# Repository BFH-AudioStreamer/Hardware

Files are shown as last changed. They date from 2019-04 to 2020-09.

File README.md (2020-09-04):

BFH Logo

# Hardware

This repository contains all the schematics and pcb designs developed for the
Audio-Streamer project. Please visit the [wiki](https://bfh-audiostreamer.github.io/Hardware) for the hardware description and 
audio measurements.

You can find PDF files of the schematics and the PCB gerber files in the Release section.

## Prerequisites
- Altium Designer

## Changes
See [CHANGELOG.md](CHANGELOG.md).

## Wiki
[To get more information about the circuits design visit the project wiki.](https://bfh-audiostreamer.github.io/Hardware)

## Authors
- Stefan Lüthi (Maintainer)

## License
Copyright Stefan Lüthi 2019.
This documentation describes Open Hardware and is licensed under the
CERN OHL v. 1.2.

You may redistribute and modify this documentation under the terms of the
CERN OHL v.1.2. (http://ohwr.org/cernohl). This documentation is distributed
WITHOUT ANY EXPRESS OR IMPLIED WARRANTY, INCLUDING OF
MERCHANTABILITY, SATISFACTORY QUALITY AND FITNESS FOR A
PARTICULAR PURPOSE. Please see the CERN OHL v.1.2 for applicable
conditions

[CERN OHL V1.2 lincese](LICENSE.md)

### Disclaimer
*Ixora.SchLib*, *Ixora.PcbLib* and the *SchDoc*s in the *Carrier-Board-Apalis* 
directory originate from Toradex. Therefore, the CERN OHL lincese does not apply:

Copyright (c) Toradex AG. All rights reserved. All data is for information 
purposes only and not guaranteed for legal purposes. Information has been 
carefully checked and is believed to beaccurate; however, no responsibility is 
assumed for inaccuracies. Brand and product names are trademarks or registered 
trademarks of their respective owners. Specifications are subject to change 
without notice.

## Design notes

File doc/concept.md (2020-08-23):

# Concept

The concept was created for standalone streamer with a touch-screen interface.

Concept

## Power Supply

The streamer can be divided into two main sections: a noisy computer section and a sensitive analog section containing the DAC. To isolate noise from the sections they are galvanically isolated.

The mains power is filtered with feed through filter to remove noise from mains. The filter AC signal is fed to a AC/DC module for the computer section and converted to DC in the analog section with a transformer/rectifier circuit. The transformer circuit with following linear regulators should result in a low noise DC supply for the DAC. A linear regulator for the computer is not feasible, due the high power consumption (ca. 5W).

## Digital/Analog Converter

The DAC is powered from a clean power supply. The digital audio stream can be sourced from I2S. The control the DAC I2C or SPI can be used, depending on the DAC selection. As sigma delta DACs typically use the I2S MCLK as system clock, a jitter free clock should be provided. This is done by the low jitter oscillators which can be selected as MCLK.

The analog signal from the DAC is passed through a filter to remove aliasing effects. The main analog output of the device are the RCA connectors. However, as most DAC output a differential signal two XLR connectors are intended on the desing.

## Computer

A computer on a module (CoM) is used to stream audio from the internet to the DAC. This prototype is based on an Apalis iMX6Quad module from Toradex. Therefore the computer section consists of the carrier board for this module.

To establish an connection to the internet ethernet and WiFi are intended. Local playback is possible over a USB interface. As the CoM also features a PCIe interface an SSD can be used as audio storage.

The streamer can be configured in standalone or server mode. In standalone mode the user can choose and control the audio playback directly on the device. A touch-screen interfaced by parallel-RGB and I2C or HDMI and USB can be used for that purpose.

## Isolation

The whole design is split into three seperate parts: the mains (230V), analog and digital section. The sections are galvanically isolated to minimize the influence between each ohter. To isolate the signals between the computer and the DAC a digital isolator can be used.

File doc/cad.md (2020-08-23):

# CAD

The CAD design was done in Autodesk Fusion 360. The case desing for the first Prottype is shown below.

<iframe src="https://outlook28079.autodesk360.com/shares/public/SH919a0QTf3c32634dcfcd85dd2a94cc4ccb?mode=embed" width="800" height="600" allowfullscreen="true" webkitallowfullscreen="true" mozallowfullscreen="true"  frameborder="0"></iframe>

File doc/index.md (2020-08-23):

# Audio-Streamer Hardware Wiki

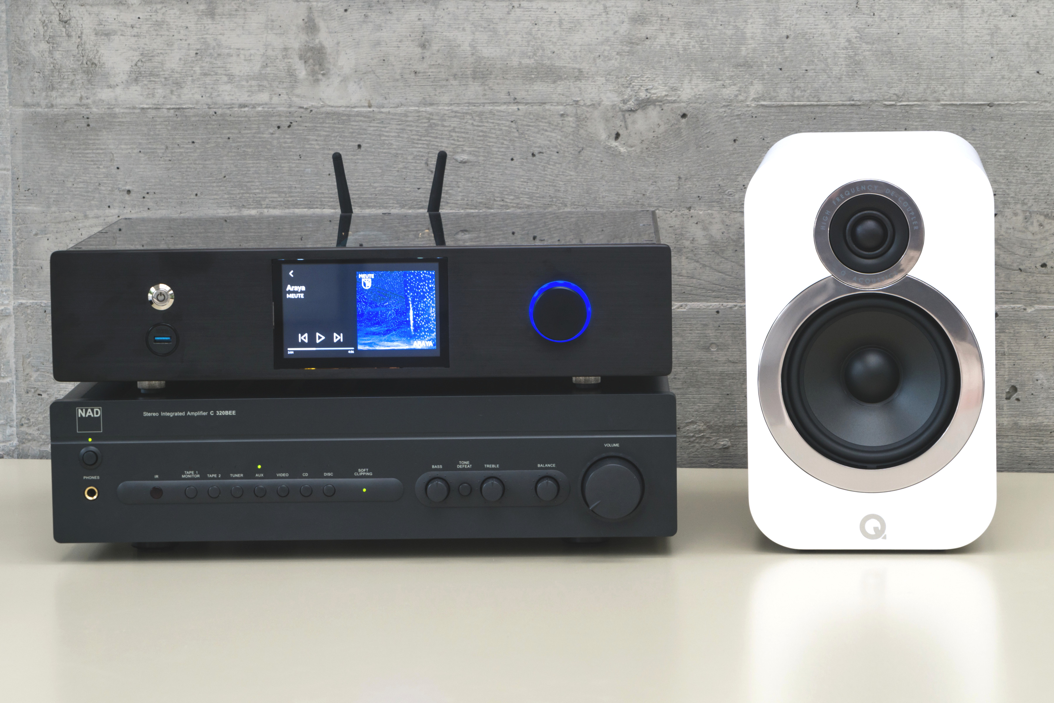
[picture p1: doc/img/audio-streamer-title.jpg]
audio-streamer-v1.0

First prototype of the audio-streamer with amplifier and speaker.

## Summary

The aim of this hardware project is to enable high-end audio equipment to play audio from streaming sources. Therefore, the audio-streamer is build with high-quality components. The modular concept allows the user/developer to change parts of the streamer to test different hardware components or to adjust the hardware to the users taste. The audio-streamer can be used with a touch-screen or as headless in HiFi rack.

## Structure

-   Concept
-   Modules
    -   Carrier boards
    -   DAC
    -   Filter
    -   Isolator
    -   Power supply
-   CAD
-   Measurements

## Present State

The second prototype (rev. 1.1) is being assembled. (2019-10-09)

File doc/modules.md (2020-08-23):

# Modules

The streamer was divided into several modules (PCBs) to be able to change to your favourite DAC or filter. But foremost to test and compare different circuit designs and component. The module groups are shown below.

## Carrier Board

A carrier board contains a socket for a module, as well as connectors for internal or external usage. They also contain the voltage regulators to supply the module.

Currently there are two carrier boards: on for the computer on a module (Toradex Apalis iMX6) and the digital to analog converter. With these two carrier boards the noisy digital and the sensitive analog circuits are separated.

## DAC

The DAC module contains an audio DAC with its circuitry. The performance of different DACs can be tested this way. Currently there exists a DAC module containing two AK4493 DACs.

## Filter

Every DAC needs a reconstruction filter. There are lots of operational amplifiers and different circuit designs available. To accommodate for the different performances the filter circuit can be swapped with a module.

## Isolator

To isolate the noisy digital circuit from the analog circuits a isolator module can be used.

## Power supply

The power supply converts mains AC to intermediate DC voltages for the carrier boards.

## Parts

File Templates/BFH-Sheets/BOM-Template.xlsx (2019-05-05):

Bill of Materials
Project: | Field=ProjectName |  |  |  |  |  | Field=Address1
 |  |  |  |  |  |  | Field=Address2
Author: | Field=DrawnBy | Revision: | Field=Revision |  |  |  | Field=Address3
Variant: | Field=VariantName | Date | Field=Date |  |  |  | Field=Address4
Column=Quantity | Column=Designator | Column=Comment | Column=Description | Column=Footprint | Column=Manufacturer Part No. | Distributor | Distributor Part No. | Price | Line Total
 |  |  |  |  |  |  |  |  | CHF 0.00
 |  |  |  |  |  |  |  |  | CHF 0.00
 |  |  |  |  |  |  |  |  | CHF 0.00
0 |  |  |  |  |  |  |  |  | CHF 0.00

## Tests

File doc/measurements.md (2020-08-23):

# Measurements

Coming as soon as the second prototype was tested.

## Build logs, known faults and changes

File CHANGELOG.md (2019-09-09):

# Changelogs

## Overview

- [Carrier-Board Apalis](#carrier-board-apalis)
- [Carrier-Board DAC](#carrier-board-dac)
- [DAC AK4493 Dual](#dac-ak4493-dual)
- [Encoder](#encoder)
- [Filter SallenKey](#filter-sk)
- [Isolator Mangetic](#isolator-mangetic)
- [Power Supply Unit](#psu)
- [Mainboard (discontinued)](#mainboard-discontinued)

## Carrier-Board Apalis

### V1.1 2019-09-09

#### Added
- Toradex Apalis carrier-board sections from [Mainboard 1.0](#mainboard-discontinued)
- Power off signal to CoM
- USB OTG interface for CoM flash access

#### Modified
- USB micro replaced by USB C connectors
- Fix footprint of HDMI2C1-6C1
- Fix schematic library error of M.2 Type B

#### Removed
- CoM signal LEDs

## Carrier-Board DAC

### V1.1 2019-09-09

#### Added
- DAC and power supply section from [Mainboard 1.0](#mainboard-discontinued)
- 0.1" connectors for DAC and filter modules

#### Modified
- Fix schematic library error of LT3094
- Fix overvoltage on voltage supervisor with voltage divider

## DAC AK4493 Dual

### V1.1 2019-09-09

#### Added
- DAC section from [Mainboard 1.0](#mainboard-discontinued)
- 5V voltage reference
- 0.1" connectors

#### Removed
- Reconstruction filter

## Encoder

### V1.0 2019-05-09

#### Added
- Rotary encoder with button
- 6 blue LEDs

## Filter SK

### V1.1 2019-09-09

#### Added
- Sallen-Key filter section from [Mainboard 1.0](#mainboard-discontinued)
- 0.1" connectors

#### Modified
- OPAMP footprint: SMD to DIP/SMD

#### Removed
- DC bias compensation

## Isolator Mangetic 

### V1.1 2019-09-09

#### Added
- Digital isolator section from [Mainboard 1.0](#mainboard-discontinued)
- 0.1" connectors

#### Modified
- SOIC wide footrpints replaced by SOIC narrow
- Fix pin mixup on the isolators

#### Removed
- Crystal oscillators

## PSU

### V1.0 2019-05-09

#### Added
- Analog power supply based on transformer, rectifier, caps
- Analog supply control with solid state relay (OptoMOS relay)
- Digital power supply based on AC/DC module

### V1.1 2019-09-09

#### Modified
- Fix schematic library error of CPC1926Y

## Mainboard (discontinued)

### V1.0 2019-05-09

#### Added
- Toradex Apalis carrier board based on the [Toradex Ixora source files](https://developer.toradex.com/products/ixora-carrier-board#design-resources)
- Net classes for high-speed signals
- Backlight control for parallel display output 
- Dual AK4493 DAC output
- Sallen-Key reconstruction filter
- Analog power supply with low noise linear regulators
- Digital signal isolation with magnetic low noise isolators
- Crystal oscillators for low jitter clock sources (22.5792 MHz and 24.5760 MHz)

#### Modified
- Apalis carrier board:
    - Minimal footprint size 0603 (imperial)
    - Altium project hierarchy changed from busses and labels to harnesses
    - Replaced obsolete components
    - M.2 connectors instead of mini PCIe connectors
    - Vertical ethernet connector instead of horizontal
    - Virtual COM port over USB instead of RS-232

#### Removed
- Apalis carrier board:
    - Fan control
    - Board ID EEPROM
    - SD card slot
    - Analog audio output
    - Camera interface
    - Resistive touch interface
    - LVDS display connector
    - CAN bus interface
    - Extension connector

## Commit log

2019-03-09 Add base project
    [Audio-Out.SchDoc, Hardware Achitecture.SchDoc, Mainboard.PrjPcb]
2019-03-09 Add Templates
    [BFH_BOM_Template.xlsm]
2019-03-09 Add Toradex Ixora Reference Board
    [Audio.SchDoc, CAN.SchDoc, Camera_Interface.SCHDOC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]
2019-03-09 Update Project File
    [Mainboard.PrjPcb]
2019-03-17 Add Audio Out
    [Audio-Out.SchDoc, Audio-Streamer-Mainboard.PcbDoc, Hardware Achitecture.SchDoc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]
2019-03-17 Add Audio Power Supply
    [Mainboard.PrjPcb]
2019-03-17 Ajust Project
    [Audio Power Supply.SchDoc, Audio-Out.SchDoc, Hardware Achitecture.SchDoc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]
2019-03-20 Add Ixora board and finish Audio-Out
    [Audio Power Supply.SchDoc, Audio-Out.SchDoc, Audio.SchDoc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]
2019-03-21 Add Isolator and improve DAC
    [Audio Power Supply.SchDoc, Audio-Out.SchDoc, DAC Interface.SchDoc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]
2019-03-24 Update Audio out and Power Supply
    [Audio Power Supply.SchDoc, Audio-Out.SchDoc]
2019-03-24 Update Analog stuff
    [Audio Power Supply.SchDoc, Audio-Out.SchDoc, DAC Interface.SchDoc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]
2019-03-30 Add Power Supply
    [Mainboard.PrjPcb, Power-Supply.PcbDoc, Power-Supply.PrjPcb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]
2019-03-30 Update Project
    [Audio Power Supply.SchDoc, Audio-Out.SchDoc, Mainboard.PrjPcb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]
2019-03-31 Update Part Numbers
    [Audio Power Supply.SchDoc, Audio-Out.SchDoc, DAC Interface.SchDoc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]
2019-04-01 Fix some schematic issues
    [Audio Power Supply.SchDoc, Audio-Out.SchDoc, DAC Interface.SchDoc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]
2019-04-02 Update all schematics
    [Audio-Out.SchDoc, DAC Interface.SchDoc, Digital Isolator.SchDoc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]
2019-04-03 Update Toradex carrier board
    [Audio Power Supply.SchDoc, Audio-Out.SchDoc, Audio.SchDoc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]
2019-04-05 Replace 0402 -> 0603 and Res, Cap Footprints
    [Audio.SchDoc, Digital Isolator.SchDoc, Ethernet.SchDoc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]
2019-04-05 Layout fitting test
    [Toradex Carrier Board.SchDoc]
2019-04-06 Update library and pcb
    [Audio-Out.SchDoc, Power_Supply.SchDoc, RGB_Display.SchDoc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]
2019-04-07 Update Designator placement
    [Audio Power Supply.SchDoc, Audio-Out.SchDoc, Mainboard.PrjPcb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]
2019-04-11 Add Muting Circuit
    [Audio Power Supply.SchDoc, Audio-Out.SchDoc, Digital Isolator.SchDoc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]
2019-04-13 Replace Connectors: USB 3.1, USB 2.0, HDMI
    [Audio Power Supply.SchDoc, Audio-Out.SchDoc, Digital Isolator.SchDoc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]
2019-04-14 Replace busses with harnesses, begin layout
    [Audio Power Supply.SchDoc, Audio-Out.SchDoc, Audio.SchDoc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]
2019-04-15 All components placed
    [Audio Power Supply.SchDoc, Audio.SchDoc, Digital Isolator.SchDoc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]
2019-04-16 Add Multiboard Assembly
2019-04-17 Swap parts, route high speed signals
    [Audio Power Supply.SchDoc, Audio-Out.SchDoc, Audio.SchDoc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]
2019-04-18 All nets connected
    [Audio Power Supply.SchDoc, Audio.SchDoc, Digital Isolator.SchDoc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]
2019-04-20 Replace Ethernet Connector
    [Audio Power Supply.SchDoc, Audio-Out.SchDoc, Digital Isolator.SchDoc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]
2019-04-22 Update Layouts
    [Audio-Out.SchDoc, Ethernet.SchDoc, HDMI.SchDoc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]
2019-04-23 Get PCB ready for production
    [Hardware Achitecture.SchDoc, Mainboard.PrjPcb, Power-Supply.PcbDoc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]
2019-04-24 Update templates
    [Audio Power Supply.SchDoc, Audio-Out.SchDoc, Audio.SchDoc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]
2019-04-25 Add OutJobs
    [Mainboard.PrjPcb, PCI_Express.SchDoc, Power-Supply.PrjPcb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]
2019-05-01 Update BOM template
    [BFH_BOM_Template.xlsm, BOM-Template.xlsx, Mainboard.PrjPcb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]
2019-05-02 Add Gerber outputs
    [Mainboard.PrjPcb, Power-Supply.PcbDoc, Power-Supply.PrjPcb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]
2019-05-03 Update assembly
2019-05-03 Update PSU Pads
    [Power-Supply.PcbDoc]
2019-05-05 Add Mainboard Variants
    [Audio-Out.SchDoc, Mainboard.PrjPcb, Power_Supply.SchDoc]
2019-05-05 Update Assemblies
    [BOM-Template.xlsx, Mainboard.PrjPcb, Power-Supply.PrjPcb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]
2019-08-12 Apply fixes and modularise project
    [Audio Power Supply.SchDoc, Audio-Out.SchDoc, Audio.SchDoc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]
2019-08-13 Finish Carrier-Board-.DAC Layout
    [Carrier-Board-Apalis.PrjPcb, Carrier-Board-DAC.PrjPcb, Output.SchDoc]
2019-08-13 Remove Toradex Ixora project
    [Audio.SchDoc, CAN.SchDoc, Camera_Interface.SCHDOC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]
2019-08-14 Add production panel
    [Audio-Streamer-Panel.PcbDoc]
2019-08-15 Fix flipped HLE footprints
    [Audio-Streamer-Panel.PcbDoc, Carrier-Board-Apalis.PrjPcb, Carrier-Board-DAC.PrjPcb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]
2019-09-09 Remove Panel
    [Audio-Streamer-Panel.PcbDoc]
2019-09-09 Update schematics revisions
    [DAC Module Interface.SchDoc, DAC.SchDoc, DAC_Interface.SchDoc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]
2019-09-09 Update Assembly drawings
    [Carrier-Board-Apalis.PrjPcb, Carrier-Board-DAC.PrjPcb, DAC-AK4493-DUAL.PrjPcb]
2019-09-23 Adjust Apalis Carrier Board Variant
    [Carrier-Board-Apalis.PrjPcb]
2019-09-23 Update PCB Project settings
    [Carrier-Board-DAC.PrjPcb, DAC-AK4493-DUAL.PrjPcb, Filter-SK.PrjPcb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]
2020-11-10 Add PCB Panel for assembly
    [MultiCB-Panel.PcbDoc, PCB-Panel-DAC.PrjPcb]
2020-11-10 Add pick&place to output job
    [Carrier-Board-Apalis.PrjPcb, DAC-AK4493-DUAL.PcbDoc]
